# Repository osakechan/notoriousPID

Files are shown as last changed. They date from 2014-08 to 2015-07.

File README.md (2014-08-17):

notoriousPID
=============
PID fermentation control for AVR platforms

notorious PID is an open source fermentation temperature control program for homebrew use.  The code has been developed with the arduino IDE.

###Contents

- [Control Overview](https://github.com/osakechan/notoriousPID#control-overview)
- [LCD Character Display](https://github.com/osakechan/notoriousPID#lcd-character-display)
- [Main Display](https://github.com/osakechan/notoriousPID#main-display)
- [User Menu](https://github.com/osakechan/notoriousPID#user-menu)
- [Additional Features](https://github.com/osakechan/notoriousPID#additonal-features)
- [Future Features](https://github.com/osakechan/notoriousPID#future-features)
- [Build Aspects](https://github.com/osakechan/notoriousPID#build-aspects)
- [List of Components](https://github.com/osakechan/notoriousPID#list-of-components)
- [Logical Connections](https://github.com/osakechan/notoriousPID#logical-connections)
- [Logical Schematic](https://github.com/osakechan/notoriousPID#logical-schematic)
- [Power Schematic](https://github.com/osakechan/notoriousPID#power-schematic)
- [Build Photos](https://github.com/osakechan/notoriousPID#build-photos)

###Control Overview
A standard PID control algorithm computes the air temperature necessary to maintain a desired fermentation setpoint. Controller output of the main PID cascades into two additional control algorithms for heating and cooling.  Final control elements consist of the refrigerator compressor and resistive heating element.  Temperature sensing of fermenting beer and chamber air is performed by the Dallas OneWire DS18B20.  The sensor's on-board DAC performs a conversion to deg C with up to 12-bit resolution (requiring approximately 650ms for conversion at room temperature).  With careful tuning of control parameters, energy efficient, precision control of desired fermentation setpoint within +/- 0.1 deg C is possible.

**Cooling** --  The refrigerator compressor is switched by a differential control algorithm with time-based overshoot prediction capabilities.  Cycles are timed to minimize compressor motor stress.

**Heating** --  A second PID instance outputs a duty cycle for time proportioned control of a resistive heating element lining the inner chamber walls.

###LCD Character Display
#####*Main Display*
main page 1&nbsp;&nbsp;&nbsp;&nbsp;&nbsp;&nbsp;main page 2

main page 3&nbsp;&nbsp;&nbsp;&nbsp;&nbsp;&nbsp;main page 4

The main display is divided amongst 4 pages.  A scroll bar on the bottom line of the LCD tracks page selection.  The first page displays an overall view consisting of program version, chamber air temperature, beer tempterature, main PID setpoint and time.  The second and third pages are dedicated to the main and heat PIDs respectively.  These pages allow the user to monitor the individual PID terms (proportional/integral/derivative) and controller output.  The fourth page displays fridge status (idle/cooling/heating), status duration and peak estimator value.  The various program states are displayed across the top line on all main views:
- display units - (C)elsius | (F)arenheit
- main PID mode - (M)anual | (A)utomatic
- heat PID mode - (M)anual | (A)utomatic
- fridge state - (I)dling | (C)ooling | (H)eating
- sd status

#####*User Menu*
menu root&nbsp;&nbsp;&nbsp;&nbsp;&nbsp;&nbsp;menu unit

menu profile

Pressing the rotary encoder pushbutton activates the user menu.  Normal PID and fridge tasks continue to run in the background.  The current menu item is indicated by the right arrow and the rotary encoder allows the user to rotate through the list of options and make a selection with the pushbutton:
- main PID mode - manual / automatic
- main PID output (manual mode required)
- main PID setpoint
- heat PID mode - manual / automatic
- heat PID output (manual mode required)
- display units - celsius / farenheit
- sd data logging - enable / disable
- sd temp profiles - select file / disable
- restore & reset - restore EEPROM settings to defaults and reset AVR
- back - finalize setting changes and leave user menu

###Additonal Features
  **EEPROM storage** -- notorious PID stores vital program states and settings in non-volatile EEPROM memory space.  If power is lost or the arduino reboots via the reset button, previous settings can be recalled from EEPROM at startup.

  **Data Logging** -- Logging functionality is provided by the Adafruit data logging shield.  The shield includes an SD card slot and a real time clock for accurate timestamping of data and files.  Logfiles are formatted as simple CSV with headers.  Logging operations may be enabled/disabled by the end user at any time via the menu.
  
  **Temperature Profiles** -- The program includes support for end-user created temperature profiles.  Profiles in CSV format may be placed in the /PROFILES/ directory of the SD card used for data logging.  Files use the 8.3 filename format with .PGM file extension and consist of comma separated pairs of setpoint temperature (deg C) and duration (hours).  During profile operation, main PID setpoint is varied according to the pairs included in the .PGM file.  Profiles may be enabled/disabled via the menu.
  
  **Watchdog Failsafe** -- An infinite loop or other AVR lock-up could lead to a loss of control of the final control elements.  To prevent an AVR failure from leading to unsafe operation, notorious PID makes use of the Watchdog timer feature of arduino (and similar) boards.  The Watchdog is an onboard countdown timer that will reboot the arduino if it has not recieved a reset pulse from the AVR within a set time.
  
###Future Features
  **WiFi Connectivity** -- Connectivity to be acomplished via the Adafruit wifi breakout with external antenna.  Data will be viewable online via the Xively service.

###Build Aspects
#####*List of Components*
- [Arduino MEGA 2560](http://arduino.cc/en/Main/arduinoBoardMega2560)
- [Adafruit data logging shield](http://www.adafruit.com/product/1141)
- [20x4 character LCD](http://www.adafruit.com/product/198)
- [Rotary encoder with pushbutton](http://www.adafruit.com/product/377)
- [SainSmart 2 channel relay board](http://www.sainsmart.com/arduino-pro-mini.html)
- 2x [DS18B20 Dallas OneWire digital temperature sensor](http://www.adafruit.com/product/381)
- [3/8" stainless thermowell](https://www.brewershardware.com/12-Stainless-Steel-Thermowell-TWS12.html)
- [A refrigerator or chest freezer](http://www.craigslist.org/about/sites)
- [Flexwatt heat tape](http://www.calorique.com/en/flexwatt-heat-tape/)

#####*Logical Connections*
| Hardware | AVR Pin | | Hardware | AVR Pin |
|---|---|---|---|---|
| LCD Enable | 8 | | Rotary A Channel | 3 |
| LCD Reset | 9 | | Rotary B Channel | 2 |
| LCD ChipSelect | 10 | | Rotary Pushbutton | A0 |
| LCD MOSI (SPI) | 11 | | OneWire Data | A1 |
| LCD MISO (SPI) | 12 | | Relay 1 (fridge) | A2 |
| LCD SCK (SPI) | 13 | | Relay 2 (beer) | A3 |
| LCD D7 | 4 | | | |
| LCD D6 | 5 | | | |
| LCD D5 | 6 | | | |
| LCD D4 | 7 | | | |

#####*Logical Schematic*
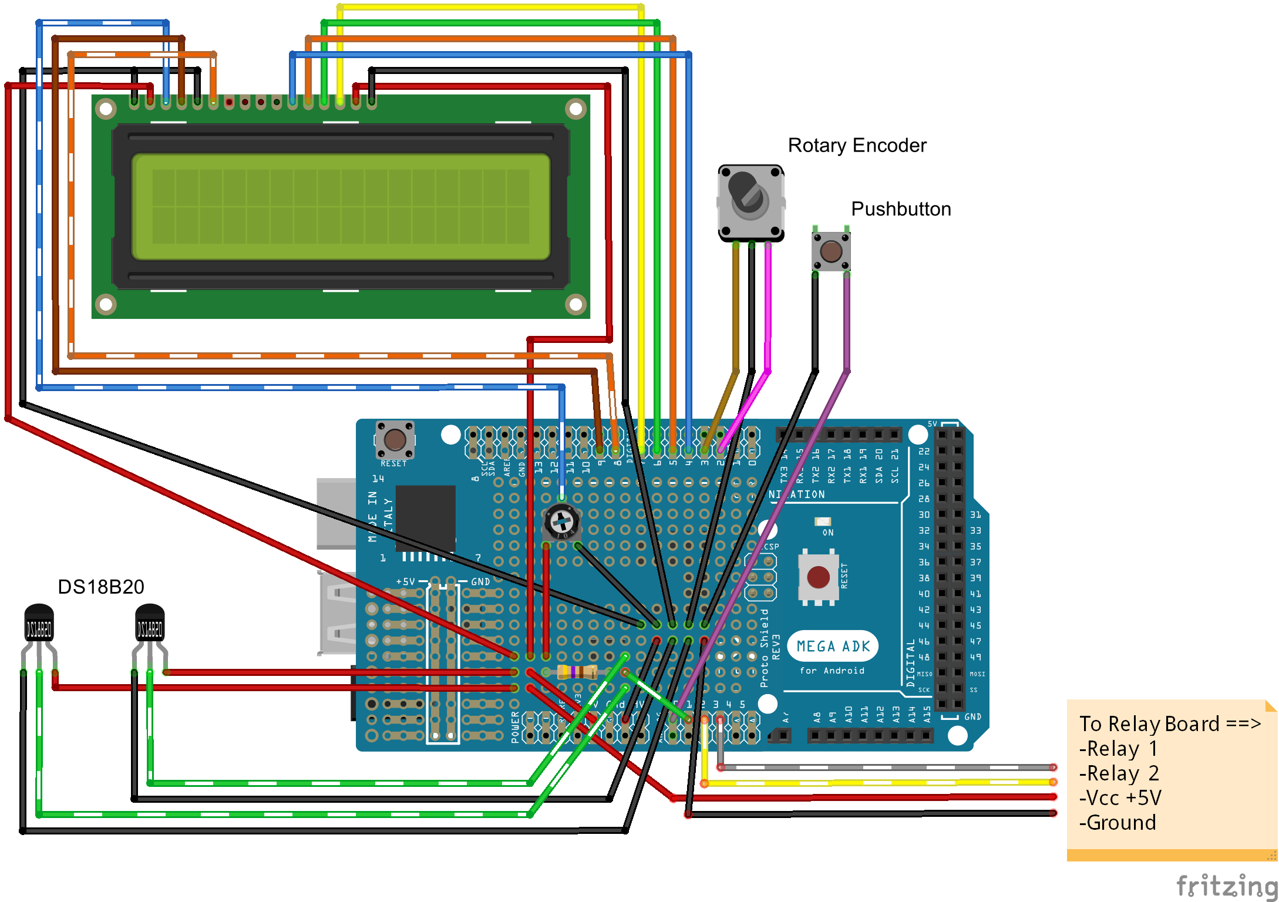
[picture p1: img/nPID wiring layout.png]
nPID logic wiring


*a couple notes about the above diagram:*
- the prototyping shield has been substituted for the adafruit data logging shield (same footprint)
- this project uses a 20x4 character lcd with backlight (shown is the stock 16x2)
- the lcd utilizes a trim-pot to adjust contrast (dashed blue wire)
- the rotary encoder from adafruit incorporates a pushbutton (shown seperate)
- the onewire data line requires a 4.7kohm pullup (dashed green wire)
- external power *must* be supplied to the onewire sensors (cannot use parasite power)
- there is no template for the sainsmart relay board but wiring should be straight-forward

#####*Power Schematic*
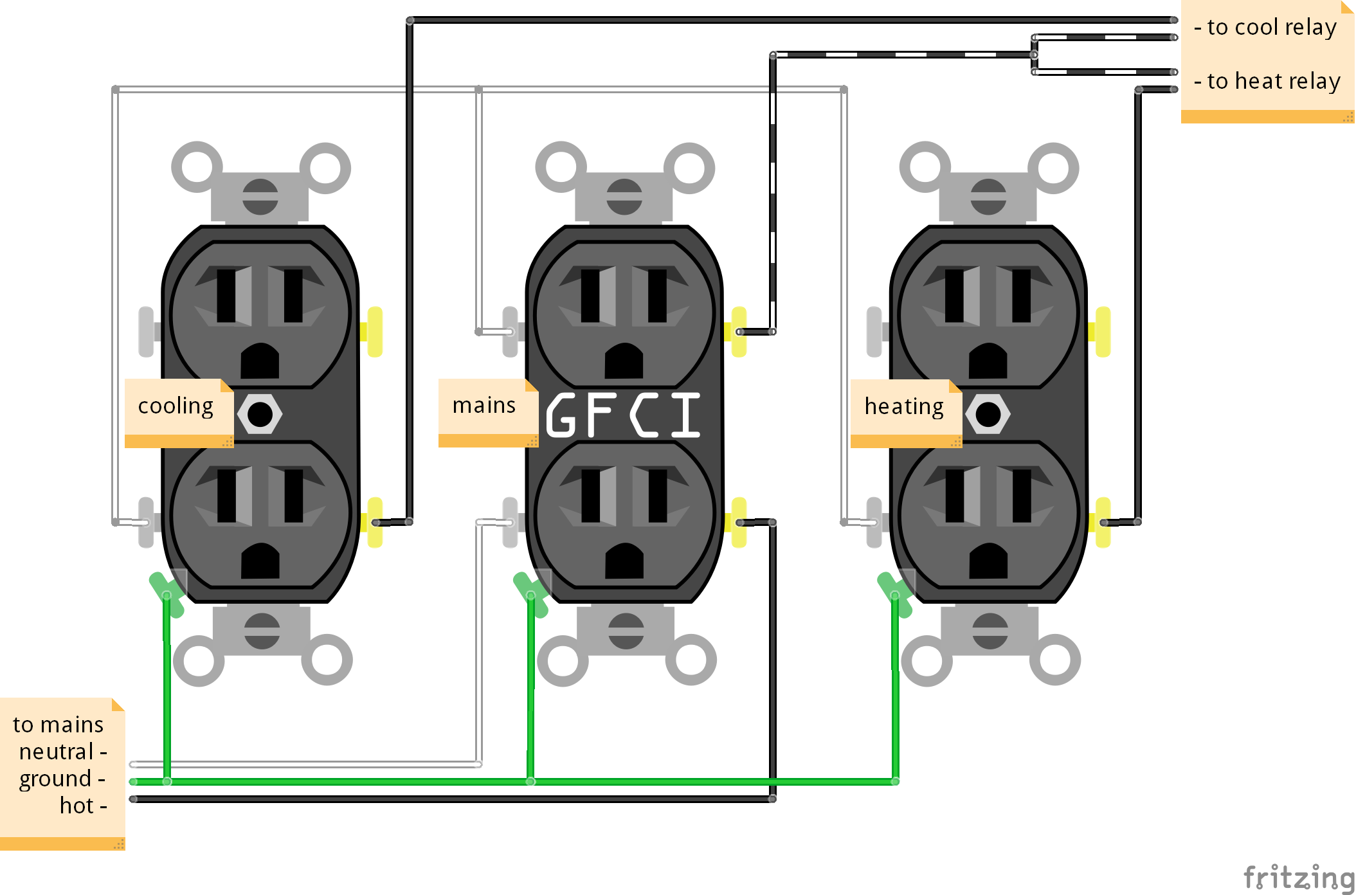
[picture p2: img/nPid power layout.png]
nPID power wiring


*a couple notes about the above diagram:*
- *mains* outlet provides project-wide GFCI protection
- plug refrigerator into *cooling* outlet (duh)
- plug heat element into *heating* outlet (duh)
- plug arduino (and optional fans, etc.) into *mains* outlet

#####*Build Photos*
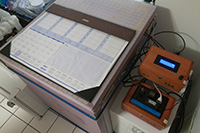
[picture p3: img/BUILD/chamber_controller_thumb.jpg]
chamber & controller
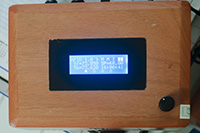
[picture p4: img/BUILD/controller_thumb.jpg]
controller
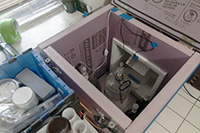
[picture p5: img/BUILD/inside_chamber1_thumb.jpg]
inside chamber view 1
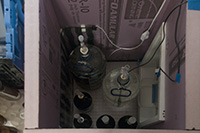
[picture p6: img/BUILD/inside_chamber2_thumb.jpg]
inside chamber view 2
&nbsp;&nbsp;&nbsp;&nbsp;&nbsp;&nbsp;&nbsp;&nbsp;&nbsp;&nbsp;&nbsp;&nbsp;

-----------------------

Many thanks go to Elco Jacobs who, without even knowing it, greatly influenced the direction of this project with his work on both [UberFridge](http://www.elcojacobs.com/uberfridge/) and [brewPI](http://www.brewpi.com/).  Also, thanks to the many helpful users on both the Arduino and Adafruit forums!

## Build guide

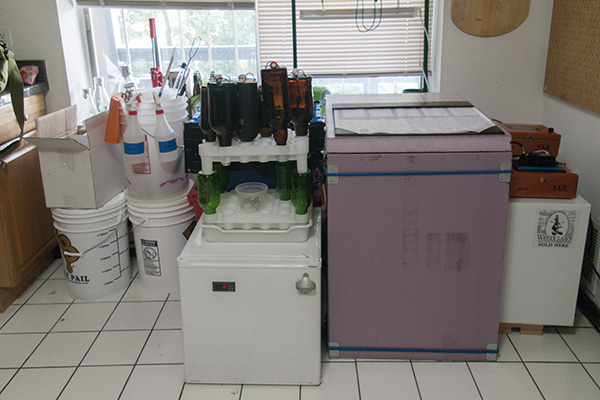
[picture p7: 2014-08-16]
img/BUILD/fermentation_space_small.jpg

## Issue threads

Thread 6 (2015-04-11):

Question: kPIDs

cobysy, 2015-04-11:
How did you arrive at the PID constants for the cooling and heating.
Do I need to tune them myself before putting into use?

osakechan, 2015-04-13:
Yes, those constants are unique to each installation and must be determined
experimentally (this is the largest challenge in configuring a PID
algorithm).  I highly recommend reading through Practical Process Control
by Doug J. Cooper (aka controlguru).  It can be found online at
http://www.controlguru.com/pages/table.html.  It is an excellent resource
and details methods for determination of the constants through a procedure
known as a bump test.  Allow the system to reach a steady state condition
at constant PID output, then 'bump' the process by changing the PID output
and observe the response of the system.  The data logging capabilities make
it easy to record this response.  It is relatively straight forward to
determine the constants from the response curve with a few simple
equations.  Good luck and Cheers!

--Mike aka Osakechan

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

cobysy, 2015-04-15:
Thank you for finding the time to write the explanation osakechan (is that from お酒ちゃん I wonder?). Especially the part about the two PID algorithms I really appreciate. Because I could never find a good resource about how to PID a fridge compressor because, as you say, it's either fully ON or OFF. In fact the same goes for the resistive heat element (aquarium heater on a glass pitcher filled with water).

I'm still waiting for a few parts to arrive - hopefully I can get it all set up soon (and before my new work). Otherwise the STC1000 will have to do.

divya0056, 2015-07-30:
Hi, I am a newbie learning more about this awesome project of yours. Wondering if you have a basic version of your project without data logging feature. So I can flash it on UNO rev3.
I am trying to make a yougurt maker and any help from your end would be much appreciated.
Thanks
Divya0056@gmail.com

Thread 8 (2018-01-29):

Question: library included

ExplodeMilk, 2018-01-29:
Hi, I am an undergraduate student who is trying to build an incubator as part of my 3D bioprinter project, your PID controller caught my attention and I would love to incorporate it into our work. However, I am not sure about the libraries you are using, particularly the <Serial.h> library you are using. Can you maybe tell me where I can download this library? Thank you!

ExplodeMilk, 2018-01-29:
Actually, after some digging, I was able to pin point the libraries:

<OneWire.h>
https://github.com/milesburton/Arduino-Temperature-Control-Library

<RTClib.h>
https://github.com/adafruit/RTClib

<SD.h>
DO NOT USE BUILT IN SD.h
https://github.com/adafruit/SD

<QueueList>
https://playground.arduino.cc/Code/QueueList#Download

<Serial.h>
Down <SoftwareSerial.h> from library manager
Change the #include <Serial.h> line to #include <SoftwareSerial.h>

<avr/wdt.h><Wire.h><SPI.h><EEPROM>
Built in within latest Arduino IDE

<LiquidCrystal.h>
Search in library manager

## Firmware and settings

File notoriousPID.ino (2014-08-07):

// Notorious PID Fermentation Temperature Control v 0.9
#include "Arduino.h"
#include <avr/wdt.h>
#include <LiquidCrystal.h>
#include <OneWire.h>
#include <Wire.h>
#include <RTClib.h>
#include <SD.h>
#include <SPI.h>
#include <OneWire.h>
#include <QueueList.h>
#include <EEPROM.h>
#include "PID_v1.h"
#include "probe.h"
#include "EEPROMio.h"
#include "fridge.h"
#include "globals.h"
#define DEBUG true  // debug flag for including debugging code

void mainUpdate();  // update sensors, PID output, fridge state, write to log, run profiles

boolean updateProfile();  // update temperature profile
void writeLog();          // write new line to log file
void dateTime(uint16_t* date, uint16_t* time);  // date/time callback function for SdFat to timestamp file creation/modification

void initDisplay();    // print static characters to LCD (lables, scrollbar, page names, etc)
void updateDisplay();  // print dynamic characters to LCD (PID/temp values, etc)

void menu();       // change PID and program settings
void mainPIDmode();  // mainPID manual/automatic
void mainPIDsp();    // mainPID setpoint
void heatPIDmode();  // heatPID manual/automatic
void dataLog();      // data logging
void tempProfile();  // temperature profiles
void tempUnit();     // temperature display units C/F
void avrReset();     // restore default settings and reset
void backOut();    // finalize changes and leave menu

void EEPROMReadSettings();   // read saved settings from EEPROM
void EEPROMWriteSettings();  // write current settings to EEPROM
void EEPROMWritePresets();   // write default settings to EEPROM

void encoderChanA();  // manage encoder pin A transitions
void encoderChanB();  // manage encoder pin B transitions

#if DEBUG == true
int freeRAM();  // approximate free SRAM for debugging
#endif

void setup() {
  pinMode(chipSelect, OUTPUT);  // select pin i/o and enable pullup resistors
  pinMode(encoderPinA, INPUT_PULLUP);
  pinMode(encoderPinB, INPUT_PULLUP);
  pinMode(pushButton, INPUT_PULLUP);
  pinMode(relay1, OUTPUT);  // configure relay pins and write default HIGH (relay open)
    digitalWrite(relay1, HIGH);
  pinMode(relay2, OUTPUT);
    digitalWrite(relay2, HIGH);
  attachInterrupt(0, encoderChanA, CHANGE);  // interrupt 0 (pin 2) triggered by change
  attachInterrupt(1, encoderChanB, CHANGE);  // interrupt 1 (pin 3) triggered by change
  encoderPos = 0;
  encoderState = 0b000;
  encoderChanA();  // call interrupt routines once to init rotary encoder
  encoderChanB();

  #if DEBUG == true  //start serial at 9600 baud for debuging
    Serial.begin(9600);
  #endif

  Wire.begin();              // initialize rtc communication
  RTC.begin();               // start real time clock
  lcd.createChar(0, (uint8_t*)delta);  // create custom characters for LCD (slots 0-7)
  lcd.createChar(1, (uint8_t*)rightArrow);
  lcd.createChar(2, (uint8_t*)disc);
  lcd.createChar(3, (uint8_t*)circle);
  lcd.createChar(4, (uint8_t*)dot);
  lcd.createChar(5, (uint8_t*)inverted);
  lcd.createChar(6, (uint8_t*)degc);
  lcd.createChar(7, (uint8_t*)degf);
  lcd.begin(20, 4);          // initialize lcd display
  if (SD.begin(chipSelect, mosi, miso, sck)) lcd.print(F("SDCard Init Success"));  // verify and initialize SD card
    else lcd.print(F("SDCard Failed/Absent"));
  delay(1500);
  SdFile::dateTimeCallback(&dateTime);

  byte ver;
  EEPROMRead(0, &ver, BYTE);  // first byte of EEPROM stores a version # for tracking stored settings
  
  #if DEBUG == true
    Serial.print(F("Current EEPROM ver:"));
    Serial.print(EEPROM_VER);
    Serial.print(F(" value read from EEPROM:"));
    Serial.println(ver);
  #endif
  
  if (ver != EEPROM_VER) {  // EEPROM version number != hard coded version number
    #if DEBUG == true
      Serial.println(F("Outdated or null EEPROM settings. Writing Defaults."));
    #endif
    
    EEPROMWritePresets();  // if version # is outdated, write presets
  }
  EEPROMReadSettings();    // load program settings from EEPROM
  #if DEBUG == true
    Serial.println(F("Settings loaded from EEPROM:"));
  #endif

  fridge.init();
  beer.init();
  
  mainPID.SetTunings(Kp, Ki, Kd);    // set tuning params
  mainPID.SetSampleTime(1000);       // (ms) matches sample rate (1 hz)
  mainPID.SetOutputLimits(0.3, 38);  // deg C (~32.5 - ~100 deg F)
  if (programState & MAIN_PID_MODE) mainPID.SetMode(AUTOMATIC);  // set man/auto
    else mainPID.SetMode(MANUAL);
  mainPID.setOutputType(FILTERED);
  mainPID.setFilterConstant(10);
  mainPID.initHistory();

  heatPID.SetTunings(heatKp, heatKi, heatKd);
  heatPID.SetSampleTime(heatWindow);       // sampletime = time proportioning window length
  heatPID.SetOutputLimits(0, heatWindow);  // heatPID output = duty time per window
  if (programState & HEAT_PID_MODE) heatPID.SetMode(AUTOMATIC);
    else heatPID.SetMode(MANUAL);
  heatPID.initHistory();

  encoderPos = 0;  // zero rotary encoder position for main loop
  
  wdt_enable(WDTO_8S);  // enable watchdog timer with 8 second timeout (max setting)
                        // wdt will reset the arduino if there is an infinite loop or other hangup; this is a failsafe device
  #if DEBUG == true
    Serial.print(F("init complete. "));
    Serial.print(millis());
    Serial.print(F("ms elapsed. "));
    Serial.print(freeRAM());
    Serial.println(F(" bytes free SRAM remaining"));
  #endif
}

void loop() {
  wdt_reset();                      // reset the watchdog timer (once timer is set/reset, next reset pulse must be sent before timeout or arduino reset will occur)
  static char listSize = 4;         // for constraining rotary encoder position
  static char lastReportedPos = 1;  // default to 1 to force display initialze on first iteration
  encoderState |= DEBOUNCE;         // reset rotary debouncer
  if (encoderPos != lastReportedPos) {
    encoderPos = (encoderPos + listSize) % listSize;  // constrain encoder position
    initDisplay();                  // re-init display on encoder position change
    lastReportedPos = encoderPos;
  }                                                    
  updateDisplay();                       // update display data
  mainUpdate();                            // subroutines manage their own timings, call every loop
  if (!digitalRead(pushButton)) menu();  // call menu routine on rotary button-press
}

void mainUpdate() {                              // call all update subroutines
  probe::startConv();                            // start conversion for all sensors
  if (probe::isReady()) {                        // update sensors when conversion complete
    fridge.update();
    beer.update();
    Input = beer.getFilter();
  }
  if (programState & TEMP_PROFILE) updateProfile();  // update main Setpoint if fermentation profile active
  mainPID.Compute();                             // update main PID
  updateFridge();                                // update fridge status
  if (programState & DATA_LOGGING) writeLog();       // if data capture enabled, run logging routine
}

boolean updateProfile() {
  static unsigned int step = 0;
  static unsigned long lastStep = 0;  // last profile step (ms)
  static profileStep Step;            // current profile step
  if ((millis() >= (unsigned long)(lastStep + Step.duration * 3600000UL)) && !profile.isEmpty()) {
    step++;                      // increment step number
    EEPROMWrite(52, step, INT);  // write step number to EEPROM
    Step = profile.pop();        // pop next step off the queue
    Setpoint = Step.temp;        // update Setpoint with new temp (deg C)
    lastStep = millis();
    return true;
  }
  return false;
}

void writeLog() {
  static double LogHz = 1;           // datalogging frequency (hz)
  static unsigned long lastLog = 0;  // millis() at last log
  if (millis() >= (unsigned long)(lastLog + 1000/LogHz)) {
    #if DEBUG == true
      Serial.print(F("logging to file... "));
      Serial.print((unsigned long)(millis() - lastLog));
      Serial.print(F("ms elapsed. "));
      Serial.print(lastLog);
      Serial.print(F(" "));
      Serial.print(freeRAM());
      Serial.println(F(" bytes free SRAM remaining"));
    #endif
  
    lastLog = millis();
    DateTime time = RTC.now();
    LogFile.print(lastLog, DEC);
    LogFile.print(F(","));
    LogFile.print(time.year(), DEC);
    LogFile.print(F("/"));
    LogFile.print(time.month(), DEC);
    LogFile.print(F("/"));
    LogFile.print(time.day(), DEC);
    LogFile.print(F(" "));
    LogFile.print(time.hour(), DEC);
    LogFile.print(F(":"));
    LogFile.print(time.minute(), DEC);
    LogFile.print(F(":"));
    LogFile.print(time.second(), DEC);
    LogFile.print(F(","));
    LogFile.print(fridge.getTemp(), DEC);
    LogFile.print(F(","));
    LogFile.print(fridge.getFilter(), DEC);
    LogFile.print(F(","));
    LogFile.print(beer.getTemp(), DEC);
    LogFile.print(F(","));
    LogFile.print(beer.getFilter(), DEC);
    LogFile.print(F(","));
    LogFile.print(Setpoint, DEC);
    LogFile.print(F(","));
    LogFile.print(Output, DEC);
    LogFile.print(F(","));
    LogFile.print(heatSetpoint, DEC);
    LogFile.print(F(","));
    LogFile.print(heatOutput, DEC);
    LogFile.print(F(","));
    LogFile.print(getPeakEstimator());
    LogFile.print(F(","));
    LogFile.println(getFridgeState(0));
    LogFile.flush();
  }
}

void dateTime(uint16_t* date, uint16_t* time) {
  DateTime now = RTC.now();
  *date = FAT_DATE(now.year(), now.month(), now.day());
  *time = FAT_TIME(now.hour(), now.minute(), now.second());
}

void initDisplay() {
  lcd.clear();
  switch (encoderPos) {
    default:
    case 0:
      lcd.print(F("nPID 1.0"));
      lcd.setCursor(1, 1);
      lcd.print(F("Tf="));
      lcd.setCursor(1, 2);
      lcd.print(F("Tb="));
      lcd.setCursor(11, 1);
      lcd.print(F("SP="));
      lcd.setCursor(5, 3);
      lcd.write((byte)2);
      lcd.write((byte)4);
      lcd.write((byte)4);
      lcd.write((byte)3);
      lcd.write((byte)4);
      lcd.write((byte)4);
      lcd.write((byte)3);
      lcd.write((byte)4);
      lcd.write((byte)4);
      lcd.write((byte)3);
      break;
      
    case 1:
      lcd.print(F("main PID"));
      lcd.setCursor(1, 1);
      lcd.print(F("tP="));
      lcd.setCursor(1, 2);
      lcd.print(F("tD="));
      lcd.setCursor(11, 1);
      lcd.print(F("tI="));
      lcd.setCursor(11, 2);
      lcd.print(F("CO="));
      lcd.setCursor(5, 3);
      lcd.write((byte)3);
      lcd.write((byte)4);
      lcd.write((byte)4);
      lcd.write((byte)2);
      lcd.write((byte)4);
      lcd.write((byte)4);
      lcd.write((byte)3);
      lcd.write((byte)4);
      lcd.write((byte)4);
      lcd.write((byte)3);
      break;

    case 2:
      lcd.print(F("heat PID"));
      lcd.setCursor(1, 1);
      lcd.print(F("tP="));
      lcd.setCursor(1, 2);
      lcd.print(F("tD="));
      lcd.setCursor(11, 1);
      lcd.print(F("tI="));
      lcd.setCursor(11, 2);
      lcd.print(F("CO="));
      lcd.setCursor(5, 3);
      lcd.write((byte)3);
      lcd.write((byte)4);
      lcd.write((byte)4);
      lcd.write((byte)3);
      lcd.write((byte)4);
      lcd.write((byte)4);
      lcd.write((byte)2);
      lcd.write((byte)4);
      lcd.write((byte)4);
      lcd.write((byte)3);
      break;
      
    case 3:
      lcd.print(F(" fridge "));
      lcd.setCursor(1, 2);
      lcd.print(F("pE="));
      lcd.setCursor(11, 2);
      lcd.write((byte)0);
      lcd.print(F("t="));
      lcd.setCursor(5, 3);
      lcd.write((byte)3);
      lcd.write((byte)4);
      lcd.write((byte)4);
      lcd.write((byte)3);
      lcd.write((byte)4);
      lcd.write((byte)4);
      lcd.write((byte)3);
      lcd.write((byte)4);
      lcd.write((byte)4);
      lcd.write((byte)2);
      break;
  }
}

void updateDisplay() {
  lcd.setCursor(9, 0);
  if (programState & DISPLAY_UNIT) lcd.write((byte)7);
    else lcd.write((byte)6);
  if (programState & TEMP_PROFILE) lcd.print(F(" PGM "));
  else {
    if (programState & MAIN_PID_MODE) lcd.print(F(" A "));
      else lcd.print(F(" M "));
    if (programState & HEAT_PID_MODE) lcd.print(F("A "));
      else lcd.print(F("M "));
  }
  if (getFridgeState(0) == IDLE) lcd.print(F("I "));
  if (getFridgeState(0) == HEAT) lcd.print(F("H "));
  if (getFridgeState(0) == COOL) lcd.print(F("C "));
  if (programState & DATA_LOGGING) lcd.print(F("SD"));
    else { lcd.write((byte)5); lcd.write((byte)5); }
  if (!encoderPos) {
    DateTime time = RTC.now();
    lcd.setCursor(11, 2);
    lcd.print((time.hour() - (time.hour() % 10))/10);
    lcd.print(time.hour() % 10);
    lcd.print(F(":"));
    lcd.print(time.minute()/10 % 6);
    lcd.print(time.minute() % 10);
    lcd.print(F(":"));
    lcd.print(time.second()/10 % 6);
    lcd.print(time.second() % 10);
  }
  if (programState & DISPLAY_UNIT) {  // temperature units = deg F
    switch (encoderPos) {         // perform conversion for display
      default:
      case 0:
        lcd.setCursor(4, 1);
        lcd.print(probe::tempCtoF(fridge.getTemp()));
        lcd.setCursor(4, 2);
        lcd.print(probe::tempCtoF(beer.getTemp()));
        lcd.setCursor(14, 1);
        lcd.print(probe::tempCtoF(Setpoint));
        break;

      case 1:
        lcd.setCursor(4, 1);
        lcd.print(mainPID.GetPTerm()*9/5);
        lcd.setCursor(4, 2);
        lcd.print(mainPID.GetDTerm()*9/5);
        lcd.setCursor(14, 1);
        lcd.print(mainPID.GetITerm()*9/5);
        lcd.setCursor(14, 2);
        lcd.print(probe::tempCtoF(Output));
        break;

      case 2:
        lcd.setCursor(4, 1);
        lcd.print(heatPID.GetPTerm()/heatWindow);
        lcd.print('%');
        lcd.setCursor(4, 2);
        lcd.print(heatPID.GetDTerm()/heatWindow);
        lcd.print('%');
        lcd.setCursor(14, 1);
        lcd.print(heatPID.GetITerm()/heatWindow);
        lcd.print('%');
        lcd.setCursor(14, 2);
        lcd.print((double)(heatOutput/heatWindow));
        lcd.print('%');
        break;

      case 3:
        double elapsed = 0;
        lcd.setCursor(0, 1);
        switch (getFridgeState(0)) {
          case IDLE:
            if (getFridgeState(1) == COOL) lcd.print(F("    wait on peak    "));
              else lcd.print(F("       idling       "));
            elapsed = (double)(millis() - getStopTime()) / 60000;   // time since IDLE start in min
            break;

          case COOL:
            lcd.print(F("       cooling      "));
            elapsed = (double)(millis() - getStartTime()) / 60000;  // time since COOL start in min
            break;

          case HEAT:
            elapsed = millis() - getStartTime();  // time since HEAT window start in ms
            if (elapsed < heatOutput) lcd.print(F("      heating      "));
              else lcd.print(F("    idle on heat    "));
            elapsed /= 60000;  // convert ms to min
            break;
        }
        lcd.setCursor(4, 2);
        lcd.print(getPeakEstimator());
        lcd.setCursor(14, 2);
        lcd.print(elapsed);
        break;
    }
  }
  else {                   // temperature units = deg C
    switch (encoderPos) {  // no conversion needed
      default:
      case 0:
        lcd.setCursor(4, 1);
        lcd.print(fridge.getTemp());
        lcd.setCursor(4, 2);
        lcd.print(beer.getTemp());
        lcd.setCursor(14, 1);
        lcd.print(Setpoint);
        break;

      case 1:
        lcd.setCursor(4, 1);
        lcd.print(mainPID.GetPTerm());
        lcd.setCursor(4, 2);
        lcd.print(mainPID.GetDTerm());
        lcd.setCursor(14, 1);
        lcd.print(mainPID.GetITerm());
        lcd.setCursor(14, 2);
        lcd.print(Output);
        break;

      case 2:
        lcd.setCursor(4, 1);
        lcd.print(heatPID.GetPTerm()/heatWindow);
        lcd.print('%');
        lcd.setCursor(4, 2);
        lcd.print(heatPID.GetDTerm()/heatWindow);
        lcd.print('%');
        lcd.setCursor(14, 1);
        lcd.print(heatPID.GetITerm()/heatWindow);
        lcd.print('%');
        lcd.setCursor(14, 2);
        lcd.print((unsigned int)heatOutput/heatWindow);
        lcd.print('%');
        break;
        
      case 3:
        double elapsed = 0;
        lcd.setCursor(0, 1);
        switch (getFridgeState(0)) {
          case IDLE:
            if (getFridgeState(1) == COOL) lcd.print(F("    wait on peak    "));
              else lcd.print(F("       idling       "));
            elapsed = (double)(millis() - getStopTime()) / 60000;   // time since IDLE start in min
            break;

          case COOL:
            lcd.print(F("       cooling      "));
            elapsed = (double)(millis() - getStartTime()) / 60000;  // time since COOL start in min
            break;

          case HEAT:
            elapsed = millis() - getStartTime();  // time since HEAT window start in ms
            if (elapsed < heatOutput) lcd.print(F("      heating      "));
              else lcd.print(F("    idle on heat    "));
            elapsed /= 60000;  // convert ms to min
            break;
        }
        lcd.setCursor(4, 2);
        lcd.print(getPeakEstimator());
        lcd.setCursor(14, 2);
        lcd.print(elapsed);
        break;
    }
  }
}

void menu() {
  #if DEBUG == true
    Serial.print(F("control suspended, entering menu... "));
    Serial.print(freeRAM());
    Serial.println(F(" bytes free SRAM remaining"));
  #endif

  static char menu_list [8][21] = {"Main PID: Mode", "Main PID: SP", "Heat PID: Mode", "[SD] Logging", "[SD] Profiles", "Display Units", "Restore & Reset", "BACK"};
  boolean exit = false;
  encoderPos = 0;
  do {wdt_reset(); mainUpdate();} while (!digitalRead(pushButton));  // wait for user to let go of button; continue to poll wdt with reset pulse
  
  do {  // main menu loop; display current menu option
    wdt_reset();
    mainUpdate();
    static char lastReportedPos = 1;
    static char listSize = 8;
    encoderState |= DEBOUNCE;
    if (lastReportedPos != encoderPos) {
      encoderPos = (encoderPos + listSize) % listSize;
      lcd.clear();
      lcd.setCursor(1, 0);
      lcd.print(menu_list[(encoderPos - 1 + listSize) % listSize]);
      lcd.setCursor(0, 1);
      lcd.write((byte)1);
      lcd.print(menu_list[encoderPos]);
      lcd.setCursor(1, 2);
      lcd.print(menu_list[(encoderPos + 1 + listSize) % listSize]);
      lcd.setCursor(1, 3);
      lcd.print(menu_list[(encoderPos + 2 + listSize) % listSize]);
      lastReportedPos = encoderPos;
    }
    if (!digitalRead(pushButton)) {
      switch (encoderPos) {  // main menu switch; run subroutine for current menu option on rotary encoder push

        case 0:  // main PID operation -- manual / automatic
          do {wdt_reset(); mainUpdate();} while (!digitalRead(pushButton));
          mainPIDmode();
          encoderPos = 0;  // return encoder position to current option on the menu
          break;

        case 1:  // main PID Setpoint
          do {wdt_reset(); mainUpdate();} while (!digitalRead(pushButton));
          mainPIDsp();
          encoderPos = 1;
          break;

        case 2:  // heat PID operation -- manual / automatic
          do {wdt_reset(); mainUpdate();} while (!digitalRead(pushButton));
          heatPIDmode();
          encoderPos = 2;
          break;
          
        case 3:  // data logging operations
          do {wdt_reset(); mainUpdate();} while (!digitalRead(pushButton));
          dataLog();
          encoderPos = 3;
          break;

        case 4:  // fermentation temperature profiles
          do {wdt_reset(); mainUpdate();} while (!digitalRead(pushButton));
          tempProfile(); 
          encoderPos = 4;
          break;

        case 5:  // temperature units C/F
          do {wdt_reset(); mainUpdate();} while (!digitalRead(pushButton));
          tempUnit();          
          encoderPos = 5;
          break;
        
        case 6:  // reset all settings to defaults and reboot arduino
          do {wdt_reset(); mainUpdate();} while (!digitalRead(pushButton));
          avrReset();
          encoderPos = 6;
          break;
          
        case 7:  // backOut of the menu and save settings; do file operations if needed
          backOut();
          exit = true;  // exit the menu loop
          break;
      }
      do {wdt_reset(); mainUpdate();} while (!digitalRead(pushButton));
      lastReportedPos += 1;  // force re-draw of menu list
    }
  } while (!exit);
  encoderPos = 0;  // zero encoder position for main display
  initDisplay();   // re-initialize main display
}
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

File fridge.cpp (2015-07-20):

#include "fridge.h"

byte fridgeState[2] = { IDLE, IDLE };      // [0] - current fridge state; [1] - fridge state t - 1 history
double peakEstimator = 30;    // to predict COOL overshoot; units of deg C per hour (always positive)
double peakEstimate = 0;      // to determine prediction error = (estimate - actual)
unsigned long startTime = 0;  // timing variables for enforcing min/max cycling times
unsigned long stopTime = 0;

void updateFridge() {        // maintain fridge at temperature set by mainPID -- COOLing with predictive differential, HEATing with time proportioned heatPID
  switch (fridgeState[0]) {  // MAIN switch -- IDLE/peak detection, COOL, HEAT routines
    default:
    case IDLE:
      if (fridgeState[1] == IDLE) {   // only switch to HEAT/COOL if not waiting for COOL peak
        if ((fridge.getFilter() > Output + fridgeIdleDiff) && ((unsigned long)((millis() - stopTime) / 1000) > coolMinOff)) {  // switch to COOL only if temp exceeds IDLE range and min off time met
          updateFridgeState(COOL);    // update current fridge status and t - 1 history
          digitalWrite(relay1, LOW);  // close relay 1; supply power to fridge compressor
          startTime = millis();       // record COOLing start time
        }
        else if ((fridge.getFilter() < Output - fridgeIdleDiff) && ((unsigned long)((millis() - stopTime) / 1000) > heatMinOff)) {  // switch to HEAT only if temp below IDLE range and min off time met
          updateFridgeState(HEAT);
          if (programState & 0b010000) heatSetpoint = Output;  // update heat PID setpoint if in automatic mode
          heatPID.Compute();      // compute new heat PID output, update timings to align PID and time proportioning routine
          startTime = millis();   // start new time proportioned window
        }
      }
      else if (fridgeState[1] == COOL) {  // do peak detect if waiting on COOL
        if (fridge.peakDetect()) {        // negative peak detected...
          tuneEstimator(&peakEstimator, peakEstimate - fridge.getFilter());  // (error = estimate - actual) positive error requires larger estimator; negative:smaller
          fridgeState[1] = IDLE;          // stop peak detection until next COOL cycle completes
        }
        else {                                                               // no peak detected
          double offTime = (unsigned long)(millis() - stopTime) / 1000;      // IDLE time in seconds
          if (offTime < peakMaxWait) break;                                  // keep waiting for filter confirmed peak if too soon
          tuneEstimator(&peakEstimator, peakEstimate - fridge.getFilter());  // temp is drifting in the right direction, but too slowly; update estimator
          fridgeState[1] = IDLE;                                             // stop peak detection
        }
      }
      break;

    case COOL:  // run compressor until peak predictor lands on controller Output
      { double runTime = (unsigned long)(millis() - startTime) / 1000;  // runtime in seconds
      if (runTime < coolMinOn) break;     // ensure minimum compressor runtime
      if (fridge.getFilter() < Output - fridgeIdleDiff) {  // temp already below output - idle differential: most likely cause is change in setpoint or long minimum runtime
        updateFridgeState(IDLE, IDLE);    // go IDLE, ignore peaks
        digitalWrite(relay1, HIGH);       // open relay 1; power down fridge compressor
        stopTime = millis();              // record idle start
        break;
      }
      if ((fridge.getFilter() - (min(runTime, peakMaxTime) / 3600) * peakEstimator) < Output - fridgeIdleDiff) {  // if estimated peak exceeds Output - differential, set IDLE and wait for actual peak
        peakEstimate = fridge.getFilter() - (min(runTime, peakMaxTime) / 3600) * peakEstimator;   // record estimated peak prediction
        updateFridgeState(IDLE);     // go IDLE, wait for peak
        digitalWrite(relay1, HIGH);
        stopTime = millis();
      }
      if (runTime > coolMaxOn) {  // if compressor runTime exceeds max on time, skip peak detect, go IDLE
        updateFridgeState(IDLE, IDLE);
        digitalWrite(relay1, HIGH);
        stopTime = millis();
      }
      break; }

    case HEAT:  // run HEAT using time proportioning
      { double runTime = millis() - startTime;  // runtime in ms
      if ((runTime < heatOutput) && digitalRead(relay2)) digitalWrite(relay2, LOW);           // active duty; close relay, write only once
        else if ((runTime > heatOutput) && !digitalRead(relay2)) digitalWrite(relay2, HIGH);  // active duty completed; rest of window idle; write only once
      if (programState & 0b010000) heatSetpoint = Output;
      if (heatPID.Compute()) {  // if heatPID computes (once per window), current window complete, start new
        startTime = millis();
      }
      if (fridge.getFilter() > Output + fridgeIdleDiff) {  // temp exceeds setpoint, go to idle to decide if it is time to COOL
        updateFridgeState(IDLE, IDLE);
        digitalWrite(relay2, HIGH);
        stopTime = millis();
      }
      break; }
  }
}

void tuneEstimator(double* estimator, double error) {  // tune fridge overshoot estimator
  if (abs(error) <= fridgePeakDiff) return;            // leave estimator unchanged if error falls within contstrained peak differential
  if (error > 0) *estimator *= constrain(1.2 + 0.03 * abs(error), 1.2, 1.5);                 // if positive error; increase estimator 20% - 50% relative to error
    else *estimator = max(0.05, *estimator / constrain(1.2 + 0.03 * abs(error), 1.2, 1.5));  // if negative error; decrease estimator 17% - 33% relative to error, constrain to non-zero value
  EEPROMWrite(38, peakEstimator, DOUBLE);              // update estimator value stored in EEPROM
}

void updateFridgeState(byte state) {  // update current fridge state
  fridgeState[1] = fridgeState[0];
  fridgeState[0] = state;
}

void updateFridgeState(byte state0, byte state1) {  // update current fridge state and history
  fridgeState[1] = state1;
  fridgeState[0] = state0;
}

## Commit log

2014-08-03 wiring layout fritzing/png
    [nPID.fzz]
2014-08-03 wiring diagram
2014-08-03 wiring notes
2014-08-03 re-push wiring image
2014-08-03 pushbutton lable
    [nPID.fzz]
2014-08-05 Revert "move definitions outside globals.h"
    This reverts commit 38de503ec3c805a0ebb9fc32cf904f264f564c22.
    [globals.h, notoriousPID.ino]
2014-08-05 Revert "Revert "move definitions outside globals.h""
    This reverts commit ce6cc697bca4e03a1d6061f10bc980603171739a.
    [globals.h, notoriousPID.ino]
2014-08-06 add function prototypes for non-arduino IDEs
2014-08-07 encoderstate defines
2014-08-09 wiring images
    [power.fzz]
2014-08-09 power circuit filename
2014-08-09 README power circuitry
2014-08-09 power circuit notes
2014-08-09 power wiring notes
2014-08-09 new power circuit
2014-08-10 wire connection highlights
2014-08-10 power notes
2014-08-10 Revert "power notes"
    This reverts commit 28038b16bee3d64ae0c650e7c1109643cc6b2f33.
2014-08-10 wiring section order
2014-08-11 encoder pins
2015-07-20 cooling time constraints and peak estimator default value
    Changes to compressor run-time constraints; increase of default peak
    estimator value; corrected comments to reflect that all back-end
    temperature computations are in deg C, not deg F.
    [fridge.cpp, fridge.h]
2015-07-20 tighten peak error constraints; increase default peak estimator
    [fridge.cpp, fridge.h]
